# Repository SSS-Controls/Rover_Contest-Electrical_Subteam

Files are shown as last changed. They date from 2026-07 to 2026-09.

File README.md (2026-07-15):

# Rover_Contest-Electrical_Subteam
This repo is for the purpose of developing the rover for the UC Davis Space and Satellite Systems Club's participation in the URC rover contest

## Downloading KiCAD
We are currently using *Kicad 10* which (as of the time of this writing) can be found at this link
https://www.kicad.org/download/
**DO NOT USE PREVIOUS VERSIONS. IF YOU DO IT MAY BREAK ALL OF THE WORK YOU DO.**

You'll be able to see the version of KiCAD on the top of the Window (Linux Mint example picture shown)


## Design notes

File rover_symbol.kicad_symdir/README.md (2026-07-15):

This folder will contain all custom symbols used in the KiCAD project.

Setup Instructions:
1. Go to: Schematic Editor > Preferences > Symbol Libraries
2. Click the plus symbol in the Symbol Libraries menu to add a new library
3. Copy the path of the symbol library from your local repository
4. Paste in the "library path" field
5. Select Library Format as "KiCad"

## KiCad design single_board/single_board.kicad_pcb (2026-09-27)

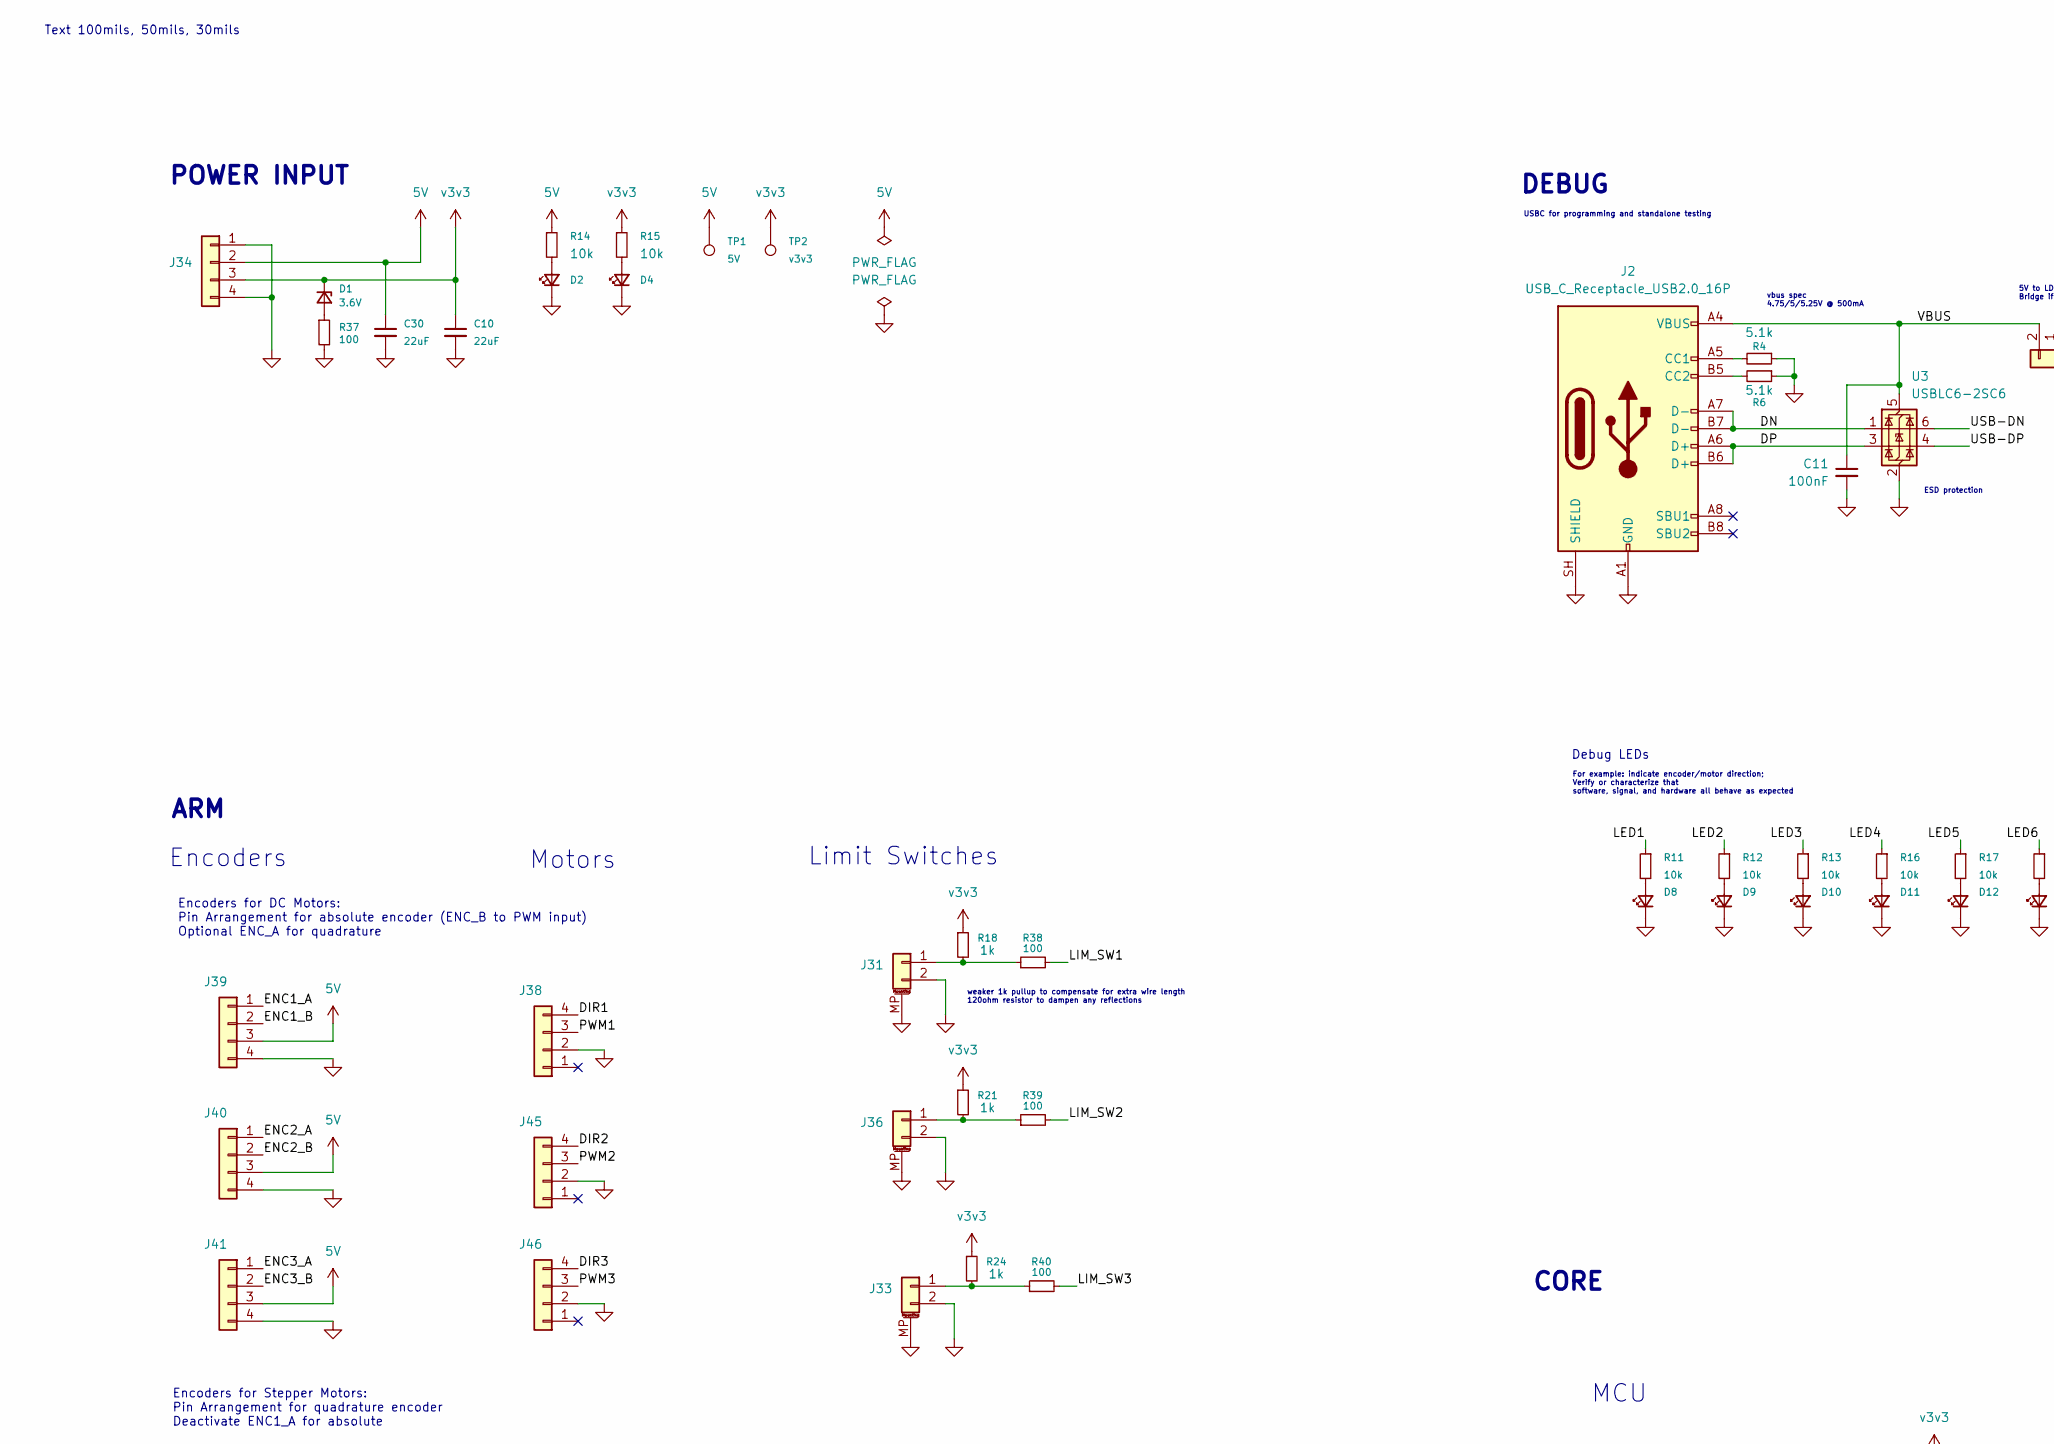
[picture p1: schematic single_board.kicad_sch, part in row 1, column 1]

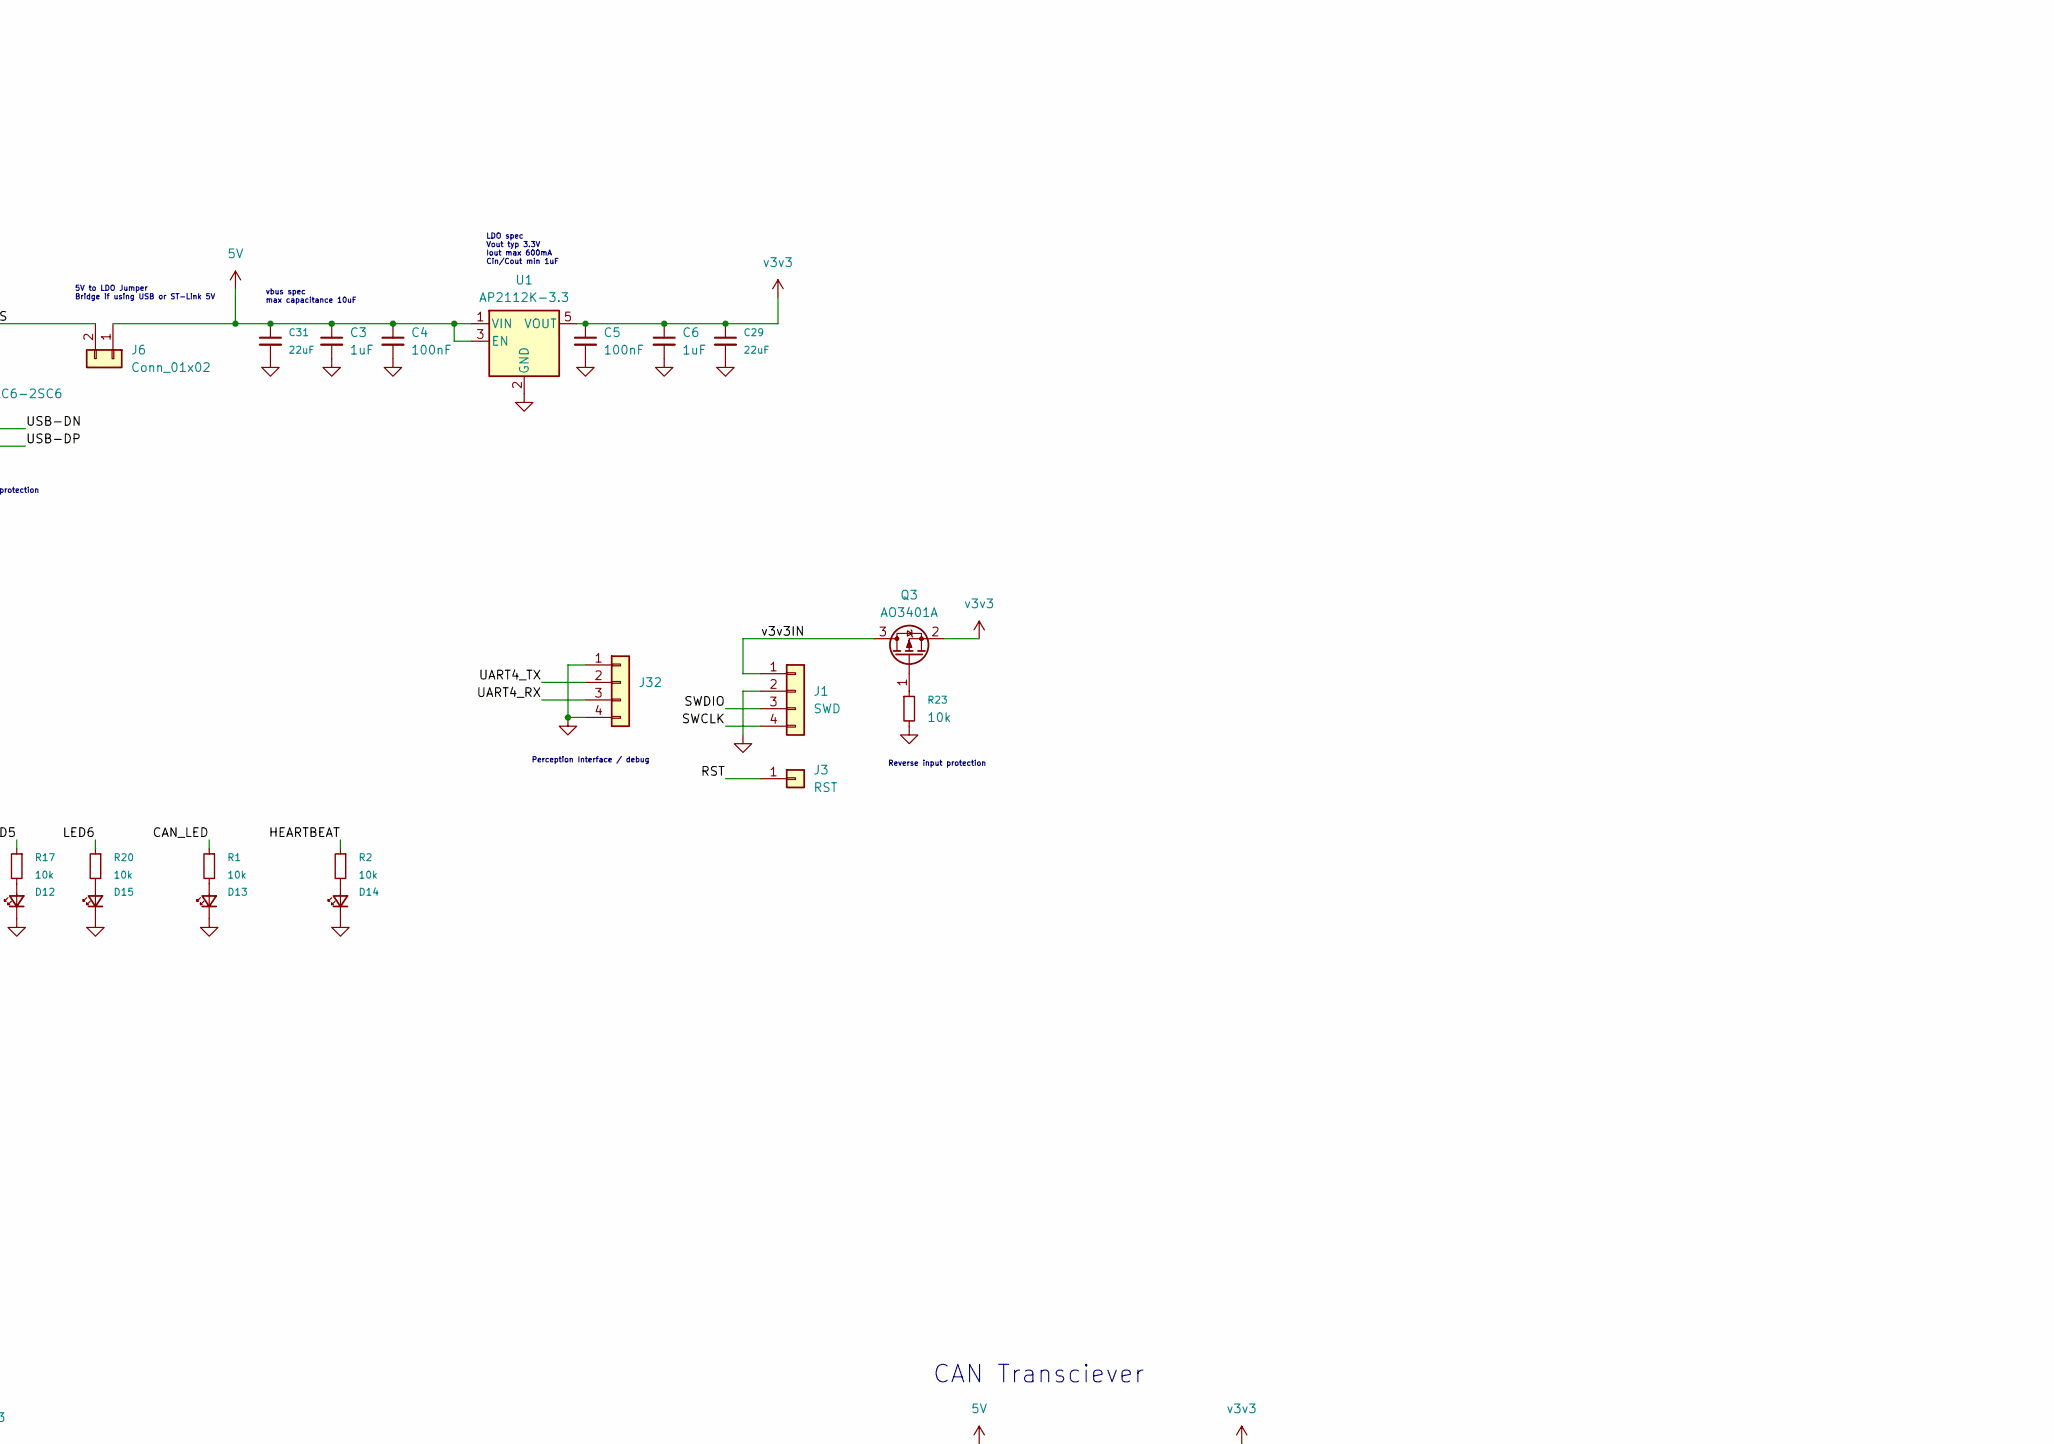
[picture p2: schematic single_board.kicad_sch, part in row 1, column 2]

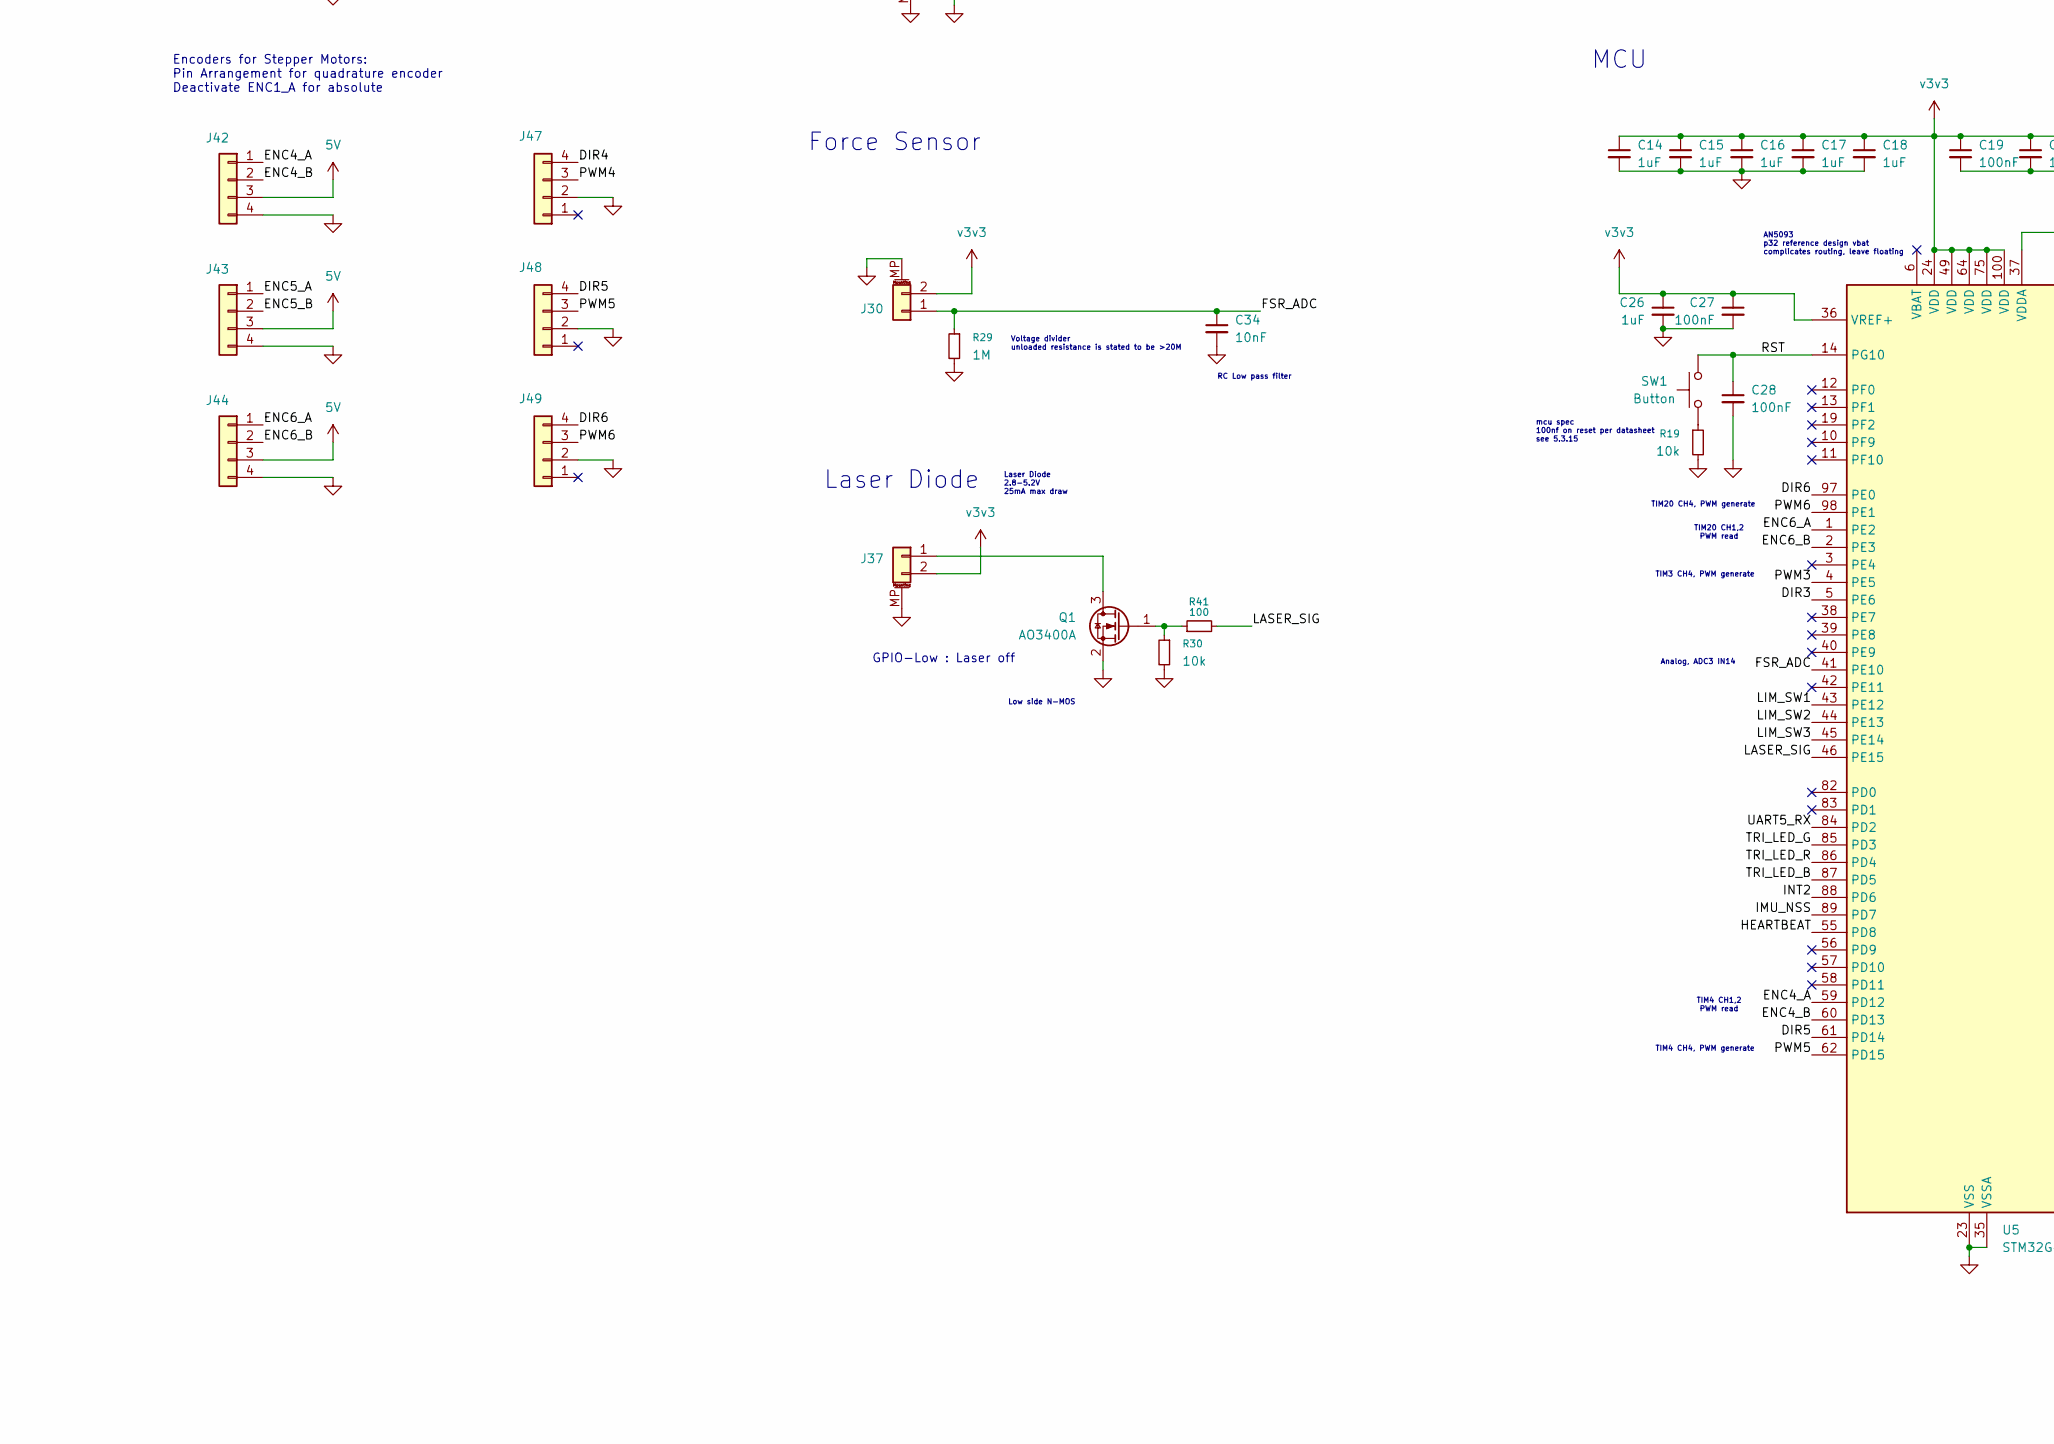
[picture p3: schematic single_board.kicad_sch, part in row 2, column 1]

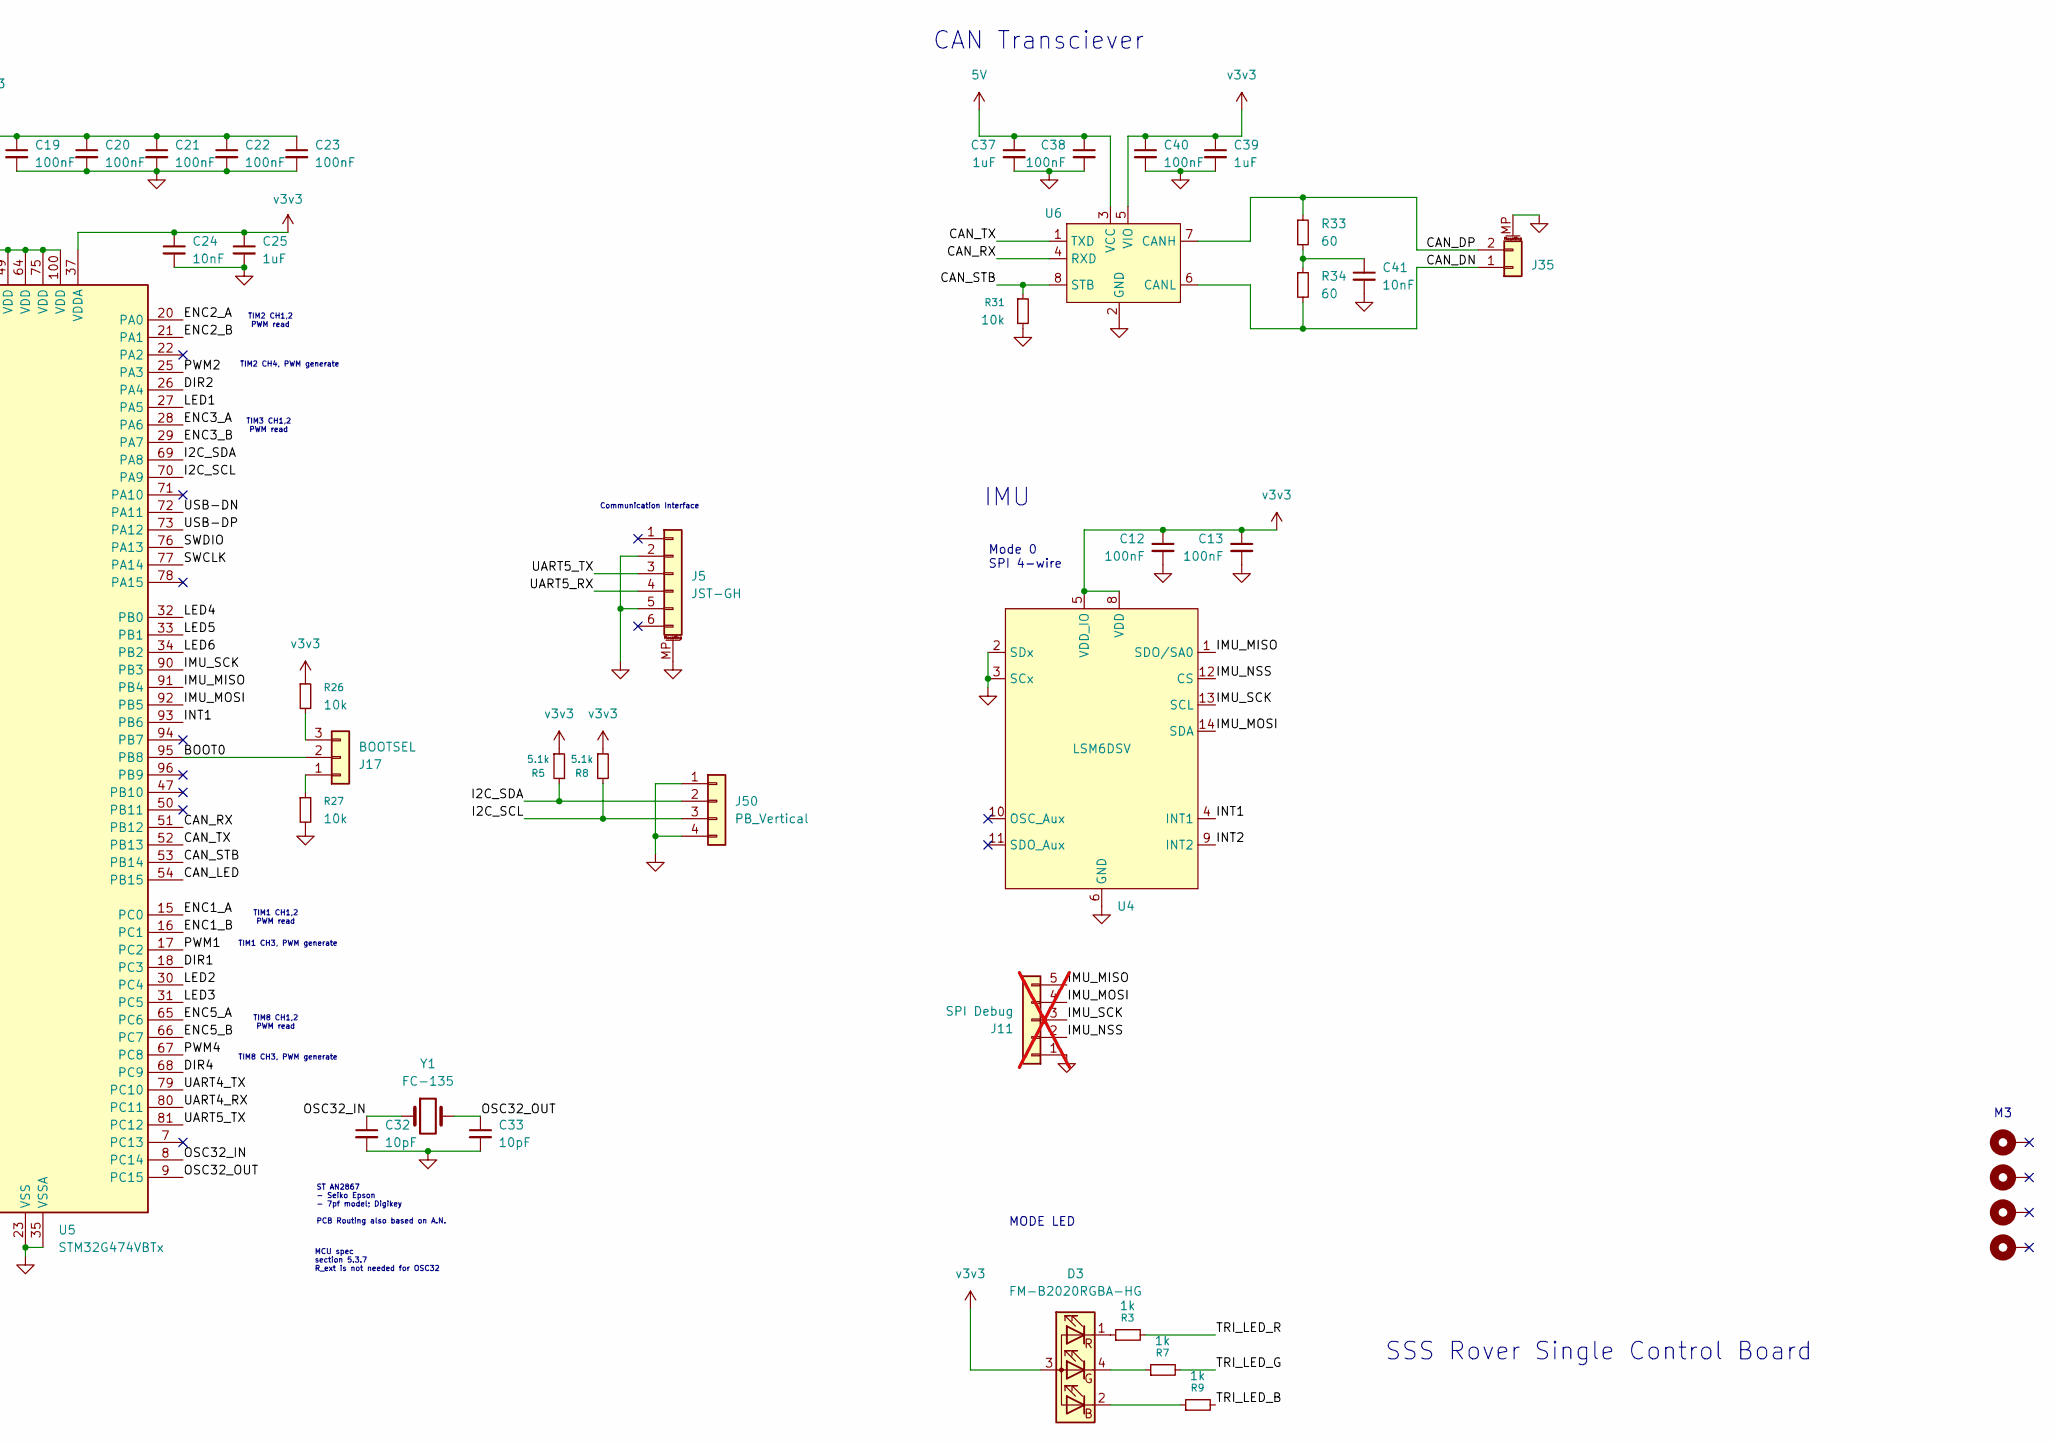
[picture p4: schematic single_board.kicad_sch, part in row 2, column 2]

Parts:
C3, C6, C14, C15, C16, C17, C18, C25, C26, C37, C39: 1uF; C_0402_1005Metric
C4, C5, C11, C12, C13, C19, C20, C21, C22, C23, C27, C28, C38, C40: 100nF; C_0402_1005Metric
C10, C29, C30, C31: 22uF; C_0805_2012Metric
C24, C34, C41: 10nF; C_0402_1005Metric
C32, C33: 10pF; C_0402_1005Metric
D1: 3.6V; SOT-23
D2, D4: LED_Small; LED_0603_1608Metric
D3: FM-B2020RGBA-HG; FM-B2020RGBA-HG Hand Solder
D8, D9, D10, D11, D12, D13, D14, D15: LED; LED_0603_1608Metric
H1, H2, H3, H4: M3; MountingHole_3.2mm_M3_Pad
J1: SWD; PinHeader_1x04_P2.54mm_Vertical
J2: USB_C_Receptacle_USB2.0_16P; USB_C_Receptacle_HRO_TYPE-C-31-M-12
J3: RST; PinHeader_1x01_P2.54mm_Vertical
J5: JST-GH; JST_GH_SM06B-GHS-TB_1x06-1MP_P1.25mm_Horizontal
J6: Conn_01x02; PinHeader_1x02_P2.54mm_Vertical
J11: SPI Debug; PinHeader_1x05_P1.27mm_Vertical; not fitted
J17: BOOTSEL; PinHeader_1x03_P2.54mm_Vertical
J30, J31, J33, J35, J36, J37: JST_GH_H; JST_GH_SM02B-GHS-TB_1x02-1MP_P1.25mm_Horizontal
J32, J34, J38, J39, J40, J41, J42, J43, J44, J45, J46, J47, J48, J49, J50: PB_Vertical; Molex_PicoBlade_53047-0410_1x04_P1.25mm_Vertical
Q1: AO3400A; SOT-23
Q3: AO3401A; SOT-23
R1, R2, R11, R12, R13, R14, R15, R16, R17, R19, R20, R23, R26, R27, R30, R31: 10k; R_0402_1005Metric
R3, R7, R9, R18, R21, R24: 1k; R_0402_1005Metric
R4, R5, R6, R8: 5.1k; R_0402_1005Metric
R29: 1M; R_0402_1005Metric
R33, R34: 60; R_0402_1005Metric
R37, R38, R39, R40, R41: 100; R_0402_1005Metric
SW1: Button; SW_SPST_PTS810
TP1: 5V; TestPoint_Pad_D1.5mm
TP2: v3v3; TestPoint_Pad_D1.5mm
U1: AP2112K-3.3; SOT-23-5
U3: USBLC6-2SC6; SOT-23-6
U4: LSM6DSV
U5: STM32G474VBTx; LQFP-100_14x14mm_P0.5mm
U6: SOIC-8_3.9x4.9mm_P1.27mm
Y1: FC-135; FC-135 Hand Solder

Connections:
5V: C3.1, C4.1, C30.1, C31.1, C37.1, C38.1, J6.1, J34.2, J39.3, J40.3, J41.3, J42.3, J43.3, J44.3, R14.1, TP1.1 (1_1), U1.1 (VIN), U1.3 (EN), U6.3 (VCC)
/BOOT0: J17.2, U5.95 (PB8)
/CAN_DN: J35.1, R34.2, U6.6 (CANL)
/CAN_DP: J35.2, R33.1, U6.7 (CANH)
/CAN_LED: R1.1, U5.54 (PB15)
/CAN_RX: U5.51 (PB12), U6.4 (RXD)
/CAN_STB: R31.1, U5.53 (PB14), U6.8 (STB)
/CAN_TX: U5.52 (PB13), U6.1 (TXD)
/DIR1: J38.4, U5.18 (PC3)
/DIR2: J45.4, U5.26 (PA4)
/DIR3: J46.4, U5.5 (PE6)
/DIR4: J47.4, U5.68 (PC9)
/DIR5: J48.4, U5.61 (PD14)
/DIR6: J49.4, U5.97 (PE0)
/DN: J2.A7 (D-), J2.B7 (D-), U3.1 (I/O1)
/DP: J2.A6 (D+), J2.B6 (D+), U3.3 (I/O2)
/ENC1_A: J39.1, U5.15 (PC0)
/ENC1_B: J39.2, U5.16 (PC1)
/ENC2_A: J40.1, U5.20 (PA0)
/ENC2_B: J40.2, U5.21 (PA1)
/ENC3_A: J41.1, U5.28 (PA6)
/ENC3_B: J41.2, U5.29 (PA7)
/ENC4_A: J42.1, U5.59 (PD12)
/ENC4_B: J42.2, U5.60 (PD13)
/ENC5_A: J43.1, U5.65 (PC6)
/ENC5_B: J43.2, U5.66 (PC7)
/ENC6_A: J44.1, U5.1 (PE2)
/ENC6_B: J44.2, U5.2 (PE3)
/FSR_ADC: C34.1, J30.1, R29.1, U5.41 (PE10)
/HEARTBEAT: R2.1, U5.55 (PD8)
/I2C_SCL: J50.3, R8.2, U5.70 (PA9)
/I2C_SDA: J50.2, R5.2, U5.69 (PA8)
/IMU_MISO: J11.5, U4.1 (SDO/SA0), U5.91 (PB4)
/IMU_MOSI: J11.4, U4.14 (SDA), U5.92 (PB5)
/IMU_NSS: J11.2, U4.12 (CS), U5.89 (PD7)
/IMU_SCK: J11.3, U4.13 (SCL), U5.90 (PB3)
/INT1: U4.4 (INT1), U5.93 (PB6)
/INT2: U4.9 (INT2), U5.88 (PD6)
/LASER_SIG: R41.2, U5.46 (PE15)
/LED1: R11.1, U5.27 (PA5)
/LED2: R12.1, U5.30 (PC4)
/LED3: R13.1, U5.31 (PC5)
/LED4: R16.1, U5.32 (PB0)
/LED5: R17.1, U5.33 (PB1)
/LED6: R20.1, U5.34 (PB2)
/LIM_SW1: R38.2, U5.43 (PE12)
/LIM_SW2: R39.2, U5.44 (PE13)
/LIM_SW3: R40.2, U5.45 (PE14)
/OSC32_IN: C32.1, U5.8 (PC14), Y1.1
/OSC32_OUT: C33.1, U5.9 (PC15), Y1.2
/PWM1: J38.3, U5.17 (PC2)
/PWM2: J45.3, U5.25 (PA3)
/PWM3: J46.3, U5.4 (PE5)
/PWM4: J47.3, U5.67 (PC8)
/PWM5: J48.3, U5.62 (PD15)
/PWM6: J49.3, U5.98 (PE1)
/RST: C28.1, J3.1 (Pin_1_1), SW1.2, U5.14 (PG10)
/SWCLK: J1.4, U5.77 (PA14)
/SWDIO: J1.3, U5.76 (PA13)
/TRI_LED_B: R9.2, U5.87 (PD5)
/TRI_LED_G: R7.2, U5.85 (PD3)
/TRI_LED_R: R3.2, U5.86 (PD4)
/UART4_RX: J32.3, U5.80 (PC11)
/UART4_TX: J32.2, U5.79 (PC10)
/UART5_RX: J5.4, U5.84 (PD2)
/UART5_TX: J5.3, U5.81 (PC12)
/USB-DN: U3.6 (I/O1), U5.72 (PA11)
/USB-DP: U3.4 (I/O2), U5.73 (PA12)
/VBUS: C11.1, J2.A4 (VBUS), J2.A9 (VBUS), J2.B4 (VBUS), J2.B9 (VBUS), J6.2, U3.5 (VBUS)
/v3v3IN: J1.1, Q3.3 (D)
GND: C3.2, C4.2, C5.2, C6.2, C10.2, C11.2, C12.2, C13.2, C14.2, C15.2, C16.2, C17.2, C18.2, C19.2, C20.2, C21.2, C22.2, C23.2, C24.2, C25.2, C26.2, C27.2, C28.2, C29.2, C30.2, C31.2, C32.2, C33.2, C34.2, C37.2, C38.2, C39.2, C40.2, C41.2, D2.1 (K), D4.1 (K), D8.1 (K), D9.1 (K), D10.1 (K), D11.1 (K), D12.1 (K), D13.1 (K), D14.1 (K), D15.1 (K), J1.2, J2.A1 (GND), J2.A12 (GND), J2.B1 (GND), J2.B12 (GND), J2.SH (SHIELD), J5.2, J5.5, J5.MP (MountPin), J11.1, J30.MP (MountPin), J31.2, J31.MP (MountPin), J32.1, J32.4, J33.2, J33.MP (MountPin), J34.1, J34.4, J35.MP (MountPin), J36.2, J36.MP (MountPin), J37.MP (MountPin), J38.2, J39.4, J40.4, J41.4, J42.4, J43.4, J44.4, J45.2, J46.2, J47.2, J48.2, J49.2, J50.1, J50.4, Q1.2 (S), R4.1, R6.1, R19.2, R23.2, R27.2, R29.2, R30.2, R31.2, R37.2, U1.2 (GND), U3.2 (GND), U4.2 (SDx), U4.3 (SCx), U4.6 (GND), U4.7 (GND), U5.23 (VSS), U5.35 (VSSA), U5.48 (VSS), U5.63 (VSS), U5.74 (VSS), U5.99 (VSS), U6.2 (GND); also elsewhere on the board
unnamed: C41.1, R33.2, R34.1
unnamed: D1.2 (A), R37.1
unnamed: D2.2 (A), R14.2
unnamed: D3.2 (BK), R9.1
unnamed: D3.4 (GK), R7.1
unnamed: D3.1 (RK), R3.1
unnamed: D4.2 (A), R15.2
unnamed: D8.2 (A), R11.2
unnamed: D9.2 (A), R12.2
unnamed: D10.2 (A), R13.2
unnamed: D11.2 (A), R16.2
unnamed: D12.2 (A), R17.2
unnamed: D13.2 (A), R1.2
unnamed: D14.2 (A), R2.2
unnamed: D15.2 (A), R20.2
unnamed: J2.A5 (CC1), R4.2
unnamed: J2.B5 (CC2), R6.2
unnamed: J17.1, R27.1
unnamed: J17.3, R26.2
unnamed: J31.1, R18.2, R38.1
unnamed: J33.1, R24.2, R40.1
unnamed: J36.1, R21.2, R39.1
unnamed: J37.1, Q1.3 (D)
unnamed: Q1.1 (G), R30.1, R41.1
unnamed: Q3.1 (G), R23.1
unnamed: R19.1, SW1.1
v3v3: C5.1, C6.1, C10.1, C12.1, C13.1, C14.1, C15.1, C16.1, C17.1, C18.1, C19.1, C20.1, C21.1, C22.1, C23.1, C24.1, C25.1, C26.1, C27.1, C29.1, C39.1, C40.1, D1.1 (K), D3.3 (A), J30.2, J34.3, J37.2, Q3.2 (S), R5.1, R8.1, R15.1, R18.1, R21.1, R24.1, R26.1, TP2.1 (1_1), U1.5 (VOUT), U4.5 (VDD_IO), U4.8 (VDD), U5.24 (VDD), U5.36 (VREF+), U5.37 (VDDA), U5.49 (VDD), U5.64 (VDD), U5.75 (VDD), U5.100 (VDD), U6.5 (VIO); also elsewhere on the board

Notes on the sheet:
Mode 0 SPI 4-wire
Voltage divider unloaded resistance is stated to be >20M
Encoders for DC Motors: Pin Arrangement for absolute encoder (ENC_B to PWM input) Optional ENC_A for quadrature
For example: indicate encoder/motor direction; Verify or characterize that software, signal, and hardware all behave as expected
Text 100mils, 50mils, 30mils
SSS Rover Single Control Board
Low side N-MOS
GPIO-Low : Laser off
IMU
Perception Interface / debug
TIM3 CH4, PWM generate
AN5093 p32 reference design vbat complicates routing, leave floating
TIM2 CH1,2 PWM read
Limit Switches
POWER INPUT
Laser Diode 2.8-5.2V 25mA max draw
MCU
Debug LEDs
MCU spec section 5.3.7 R_ext is not needed for OSC32
5V to LDO Jumper Bridge if using USB or ST-Link 5V
TIM8 CH3, PWM generate
ESD protection
Communication Interface
RC Low pass filter
Encoders
TIM1 CH3, PWM generate
Encoders for Stepper Motors: Pin Arrangement for quadrature encoder Deactivate ENC1_A for absolute
MODE LED
ST AN2867 - Seiko Epson - 7pf model; Digikey PCB Routing also based on A.N.
DEBUG
vbus spec max capacitance 10uF
TIM2 CH4, PWM generate
LDO spec Vout typ 3.3V Iout max 600mA Cin/Cout min 1uF
TIM4 CH4, PWM generate
ARM
USBC for programming and standalone testing
TIM3 CH1,2 PWM read
TIM20 CH4, PWM generate
mcu spec 100nf on reset per datasheet see 5.3.15
Reverse input protection

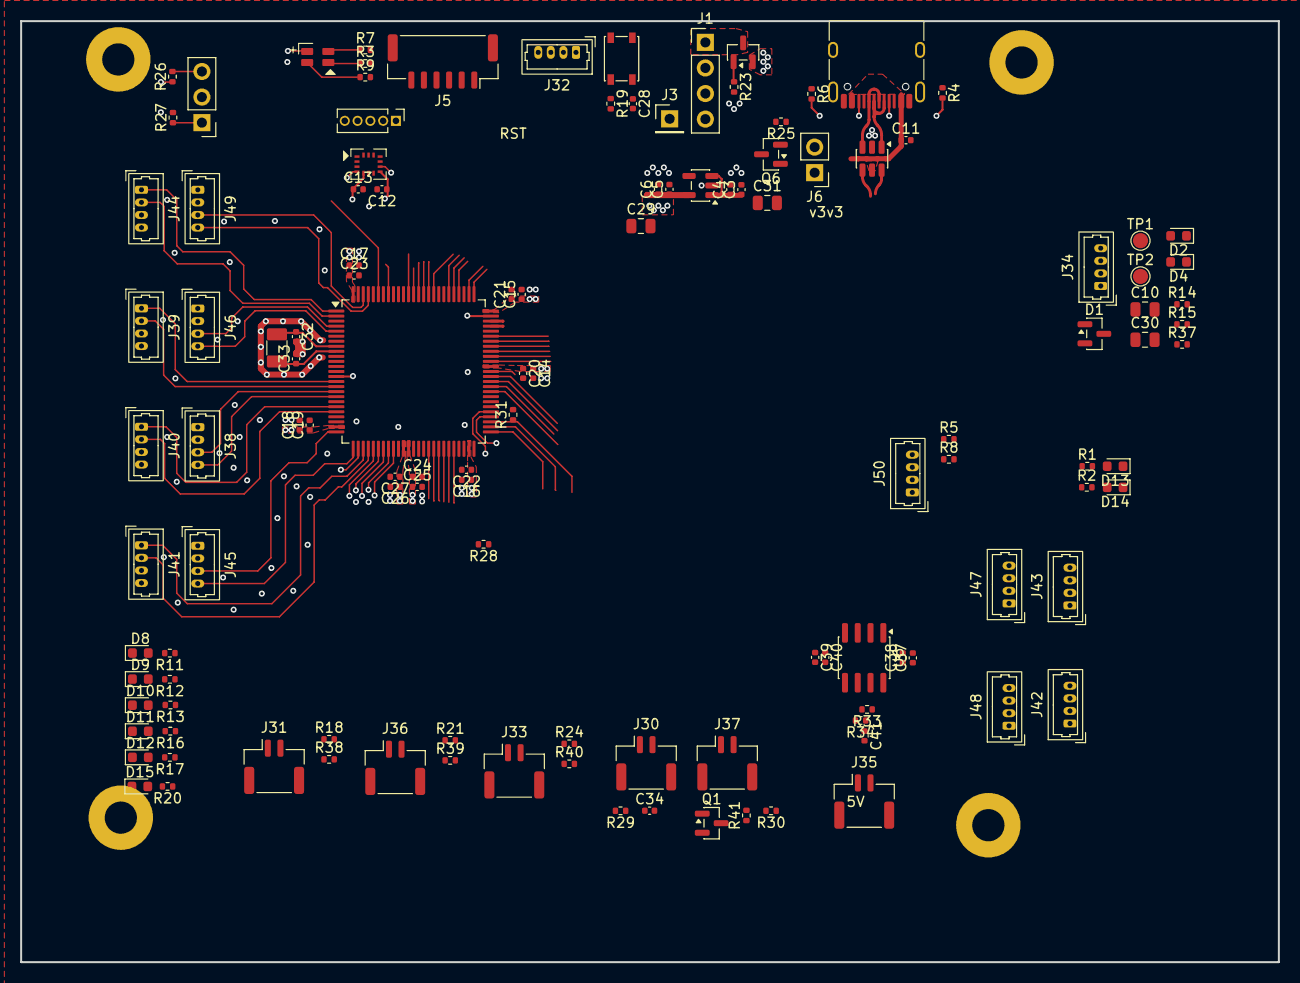
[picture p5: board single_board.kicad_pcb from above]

Board: 4 copper layers, 124.9 x 93.4 mm, 126 parts (0 on the bottom side), 99 nets.

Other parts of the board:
Q6: AO3401A; SOT-23
R25, R28: 10k; R_0402_1005Metric

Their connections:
GND: R25.2; also elsewhere on the board
unnamed: Q6.1 (G), R25.1
v3v3: R28.2; also elsewhere on the board

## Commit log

2026-07-09 Update README.md
    Added description for downloading KiCAD
2026-07-10 Created KiCad Project
    Added LDO and power LEDs
    [testPCB.kicad_pcb, testPCB.kicad_sch]
2026-07-10 Adding footprint USBC
2026-07-10 Add footprint USBC
2026-07-11 0402 Footprints
    Updated 1uF caps, 10k resistors, and diodes to 0402.
    [testPCB.kicad_sch]
2026-07-15 Added IMU to libraries
    IMU footprint and symbol added to libraries.
    [testPCB.kicad_pcb, testPCB.kicad_sch]
2026-07-16 ADD: Added in the USB connector, again.
2026-07-16 ADD: Added another IMU to the schematic
    [testPCB.kicad_sch]
2026-07-17 Testing Changes
    Verifying library functionalities
    [testPCB.kicad_pcb, testPCB.kicad_sch]
2026-08-05 New Project File
    Copied Drivebase Board design
    [single_board.kicad_pcb, single_board.kicad_sch, testPCB.kicad_pcb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]
2026-08-05 Clean up copied schematic
    [single_board.kicad_sch]
2026-08-05 Organize Files
    [single_board.kicad_pcb, single_board.kicad_sch]
2026-08-05 Updated Power Scheme
    + USBC
    + Fuse
    + Power flags
    + Power symbols, VBUS, 5V, v3v3
    [single_board.kicad_sch]
2026-08-10 All elements added
    MCU Pinout
    GPIO
    IMU Pinout
    [single_board.kicad_pcb, single_board.kicad_sch]
2026-08-10 Change MCU Power
    4.7uf into individual 1uf
    Change reverse polarity protection diodes
    [single_board.kicad_pcb, single_board.kicad_sch]
2026-08-10 Added new footprints
    Tri color led
    Crystal
    Debug
    IMU
    [single_board.kicad_pcb, single_board.kicad_sch]
2026-08-10 Edit pin headers
    Pinout optimized for encoders
    High side p-mos for fsr input
    [single_board.kicad_pcb, single_board.kicad_sch]
2026-08-10 Fix Laser and FSR switches
    Appropriate pull up/down resistors
    Remove in line resistors
    [single_board.kicad_pcb, single_board.kicad_sch]
2026-08-11 P-Mos reverse polarity protection
    removed fuse and schottky diode
    shrink bom, keep reverse polarity protection on 5v and 3.3v lines
    [single_board.kicad_pcb, single_board.kicad_sch]
2026-08-12 Rough Placement
    changes to schematic:
    8pf to 10pf on crystal
    2.54mm pitch screw terminals
    can standby pin
    shuffle other pinouts
    [single_board.kicad_pcb, single_board.kicad_sch]
2026-08-12 Updated Footprints and Pinouts
    Terminal blocks
    8pf
    MCU pinout
    [single_board.kicad_sch]
2026-08-12 Fix IDC
    SMD pad to through hole
2026-08-12 Layout pass 2
    Rough placement of components and orientations
    [single_board.kicad_pcb, single_board.kicad_sch]
2026-08-12 Consolidate BOM
    Use same 2 pin terminal blocks
    [single_board.kicad_sch]
2026-08-12 Crystal and 4 Driver/Encoder Sets
    [single_board.kicad_pcb]
2026-08-12 End effector gpio
    [single_board.kicad_pcb]
2026-08-12 Layout pass 3
    [single_board.kicad_pcb, single_board.kicad_sch]
2026-08-12 Signal Traces
    [single_board.kicad_pcb, single_board.kicad_sch]
2026-08-12 Diff pairs, layer 1 power
    Net classes and rules
    [single_board.kicad_pcb, single_board.kicad_sch]
2026-08-12 All sig
    todo: power, silkscreen, vias
    [single_board.kicad_pcb]
2026-08-12 Layout satisfactory
    todo: vias, silkscreen
    [single_board.kicad_pcb]
2026-08-12 Merge
    also fix idc footprint again
    [single_board.kicad_pcb]
2026-08-19 Update Schematic
    New footprints
    Clean up schematic
    [single_board.kicad_pcb, single_board.kicad_sch]
2026-08-21 I2C, connectors
    Update connectors, add I2C bus to MCU
    TODO: routing new connectors
    [single_board.kicad_pcb, single_board.kicad_sch]
2026-08-21 Clear Routing
    Clear previous routing, preparation for new picoblade and jst gh connectors
    [single_board.kicad_pcb, single_board.kicad_sch]
2026-08-21 M8 mounting holes
    better picoblade arrangement
    [single_board.kicad_pcb, single_board.kicad_sch]
2026-08-24 Setup
    Minor adjustments before handoff
    [single_board.kicad_pcb]
2026-08-28 Updated connectors
    2MMCX for comms uart, picoblade for i2c
    [single_board.kicad_pcb, single_board.kicad_sch]
2026-08-28 Adjust connector pinouts
    [single_board.kicad_pcb, single_board.kicad_sch]
2026-09-05 M3 mounting holes
    [single_board.kicad_pcb, single_board.kicad_sch]
2026-09-05 UART to picoblade
    [single_board.kicad_sch]
2026-09-06 UART picoblades
    [single_board.kicad_pcb, single_board.kicad_sch]
2026-09-06 Remove excess protection FETs
    [single_board.kicad_pcb, single_board.kicad_sch]
2026-09-09 Debug and Power
    [single_board.kicad_pcb, single_board.kicad_sch]
2026-09-09 boxes on schematic
    [single_board.kicad_sch]
2026-09-09 Remove Decoupling Capacitors
    Remove 100nF on encoder connector
    Added additinoal LEDS
    Connector Routing
    [single_board.kicad_pcb, single_board.kicad_sch]
2026-09-09 Layout and LEDS
    _sch: change order of led and resistor
    low pass filter for FSR adc
    adjust gh2pin connector orientations on force sensor and laser
    _pcb: layout of left side motor control
    organization of leds
    [single_board.kicad_pcb, single_board.kicad_sch]
2026-09-11 UART5 to JST-GH
    Change UART5 Connector to 6 pin JST-GH
    [single_board.kicad_pcb, single_board.kicad_sch]
2026-09-15 Picoblade 3D Model
    [Molex_PicoBlade_53047-0410.stp, single_board.kicad_pcb]
2026-09-15 Revert "Picoblade 3D Model"
    This reverts commit 7f724f2476444bdc69c77aaaca81da4394cbdc2a.
    [Molex_PicoBlade_53047-0410.stp, single_board.kicad_pcb]
2026-09-21 Schematic
    Larger schematic sheet
    Power input zener diode
    22uF bulk capacitors
    Replace 120 ohm with 100 ohm resistors
    CAN Split termination
    More consistent net labels
    Remove USBC Protection FET
    Additional debug LED to match number of motor input pairs
    [single_board.kicad_pcb, single_board.kicad_sch]
2026-09-27 Schematic changes
    5.1k to 0402 footprint
    I2C pullup resistors
    Adjust force sensor circuitry
    Replace NMOS
    FSR and Limit switch pinout adjustment
    [single_board.kicad_pcb, single_board.kicad_sch]
